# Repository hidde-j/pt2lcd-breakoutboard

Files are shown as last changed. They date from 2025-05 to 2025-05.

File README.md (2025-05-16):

# pt2lcd-breakoutboard
Simple LPM015M135A breakout board 

#### Voltage regulator

The LPM015M135A expects 4.5V on VDDP, so an LT3009 voltage regulator is included in the design that steps 5V down to 4.5V.

#### Missing footprints/symbols

The BM20B-24DS and LT3009 footprints are not included due to copyright reasons. These can be found by searching for the part numbers on Digikey. These are the expected file locations:

```
.
├── BM20B-24DS
│   ├── 2024-12-25_12-01-17.kicad_sym
│   ├── BM20B(0.6)-24DS-0.4V(53).STEP
│   └── footprints.pretty
│       └── BM20B0.6-24DS-0.4V53_HIR.kicad_mod
├── LT3009
│   ├── 2024-12-23_21-50-19.kicad_sym
│   ├── 3009fd.pdf
│   └── footprints.pretty
│       ├── DFN-6_DC_LIT.kicad_mod
│       ├── DFN-6_DC_LIT-L.kicad_mod
│       └── DFN-6_DC_LIT-M.kicad_mod
```

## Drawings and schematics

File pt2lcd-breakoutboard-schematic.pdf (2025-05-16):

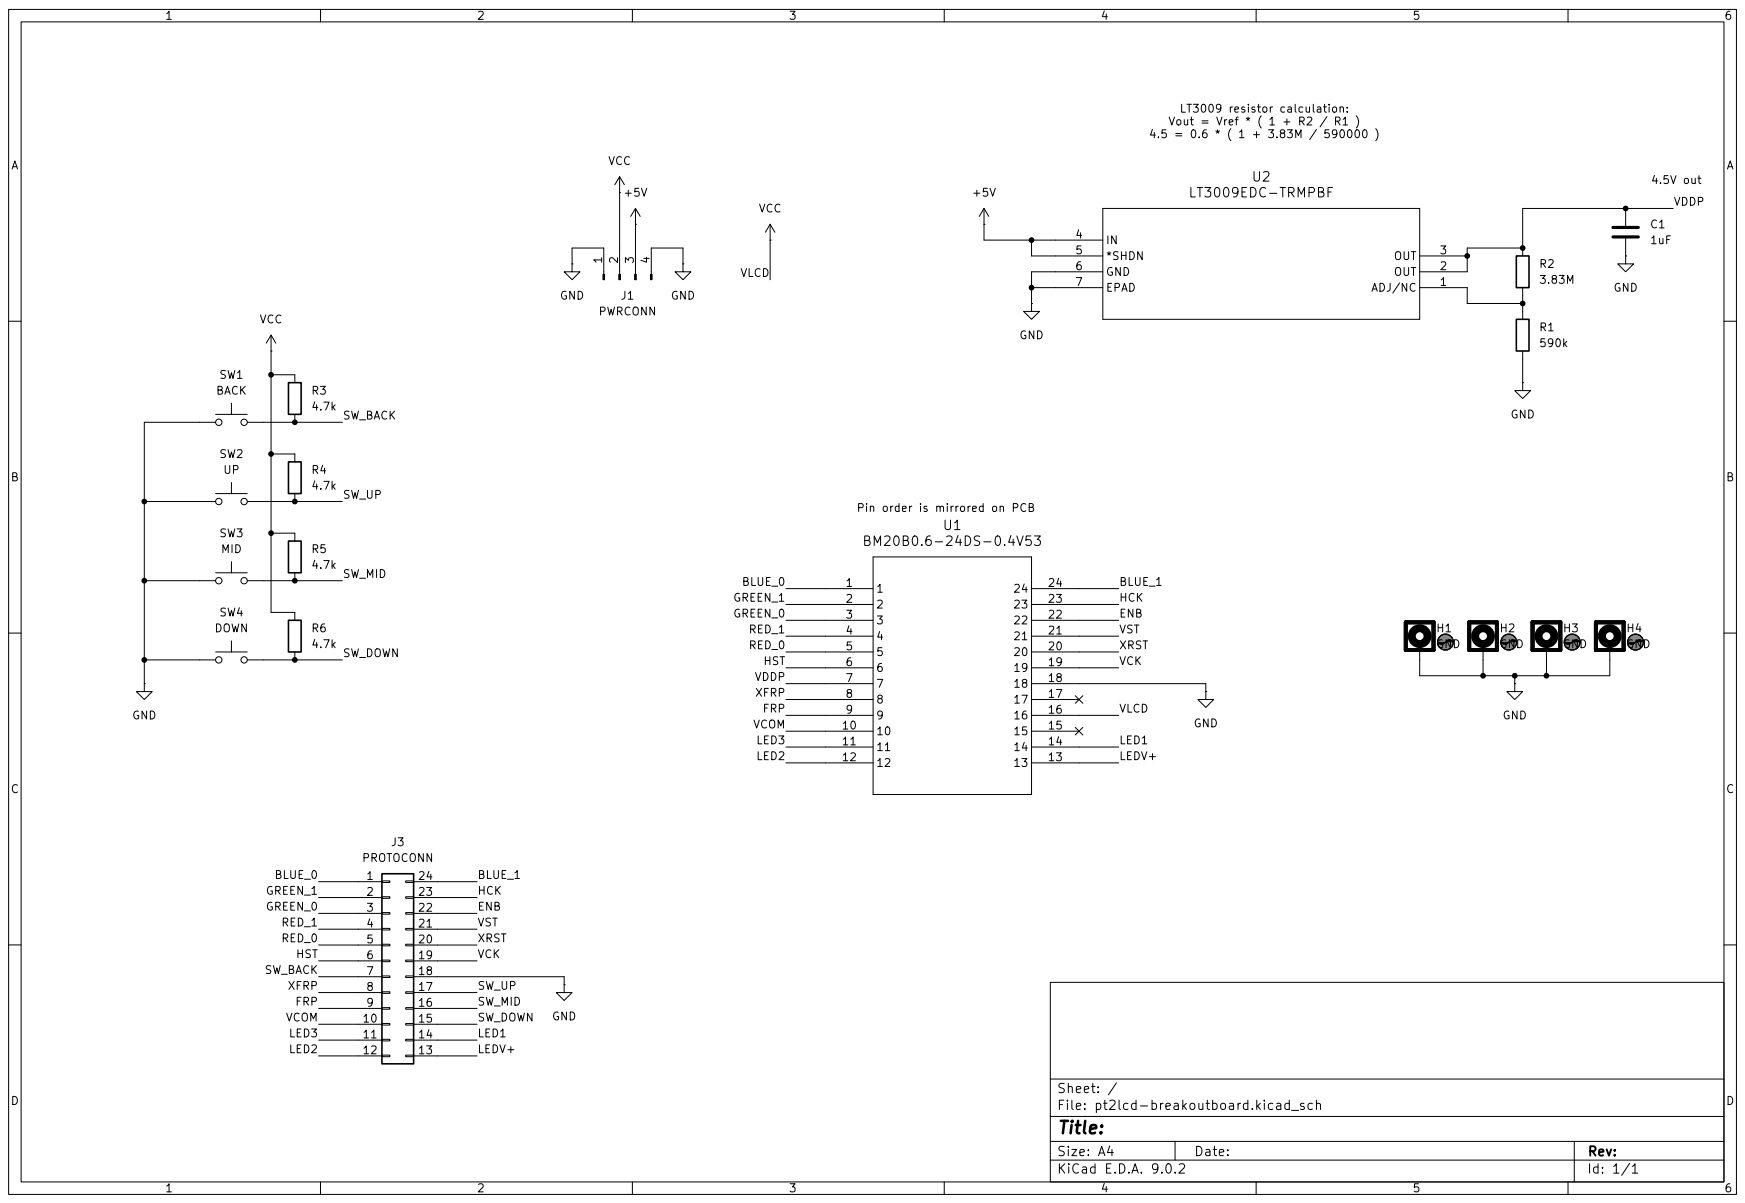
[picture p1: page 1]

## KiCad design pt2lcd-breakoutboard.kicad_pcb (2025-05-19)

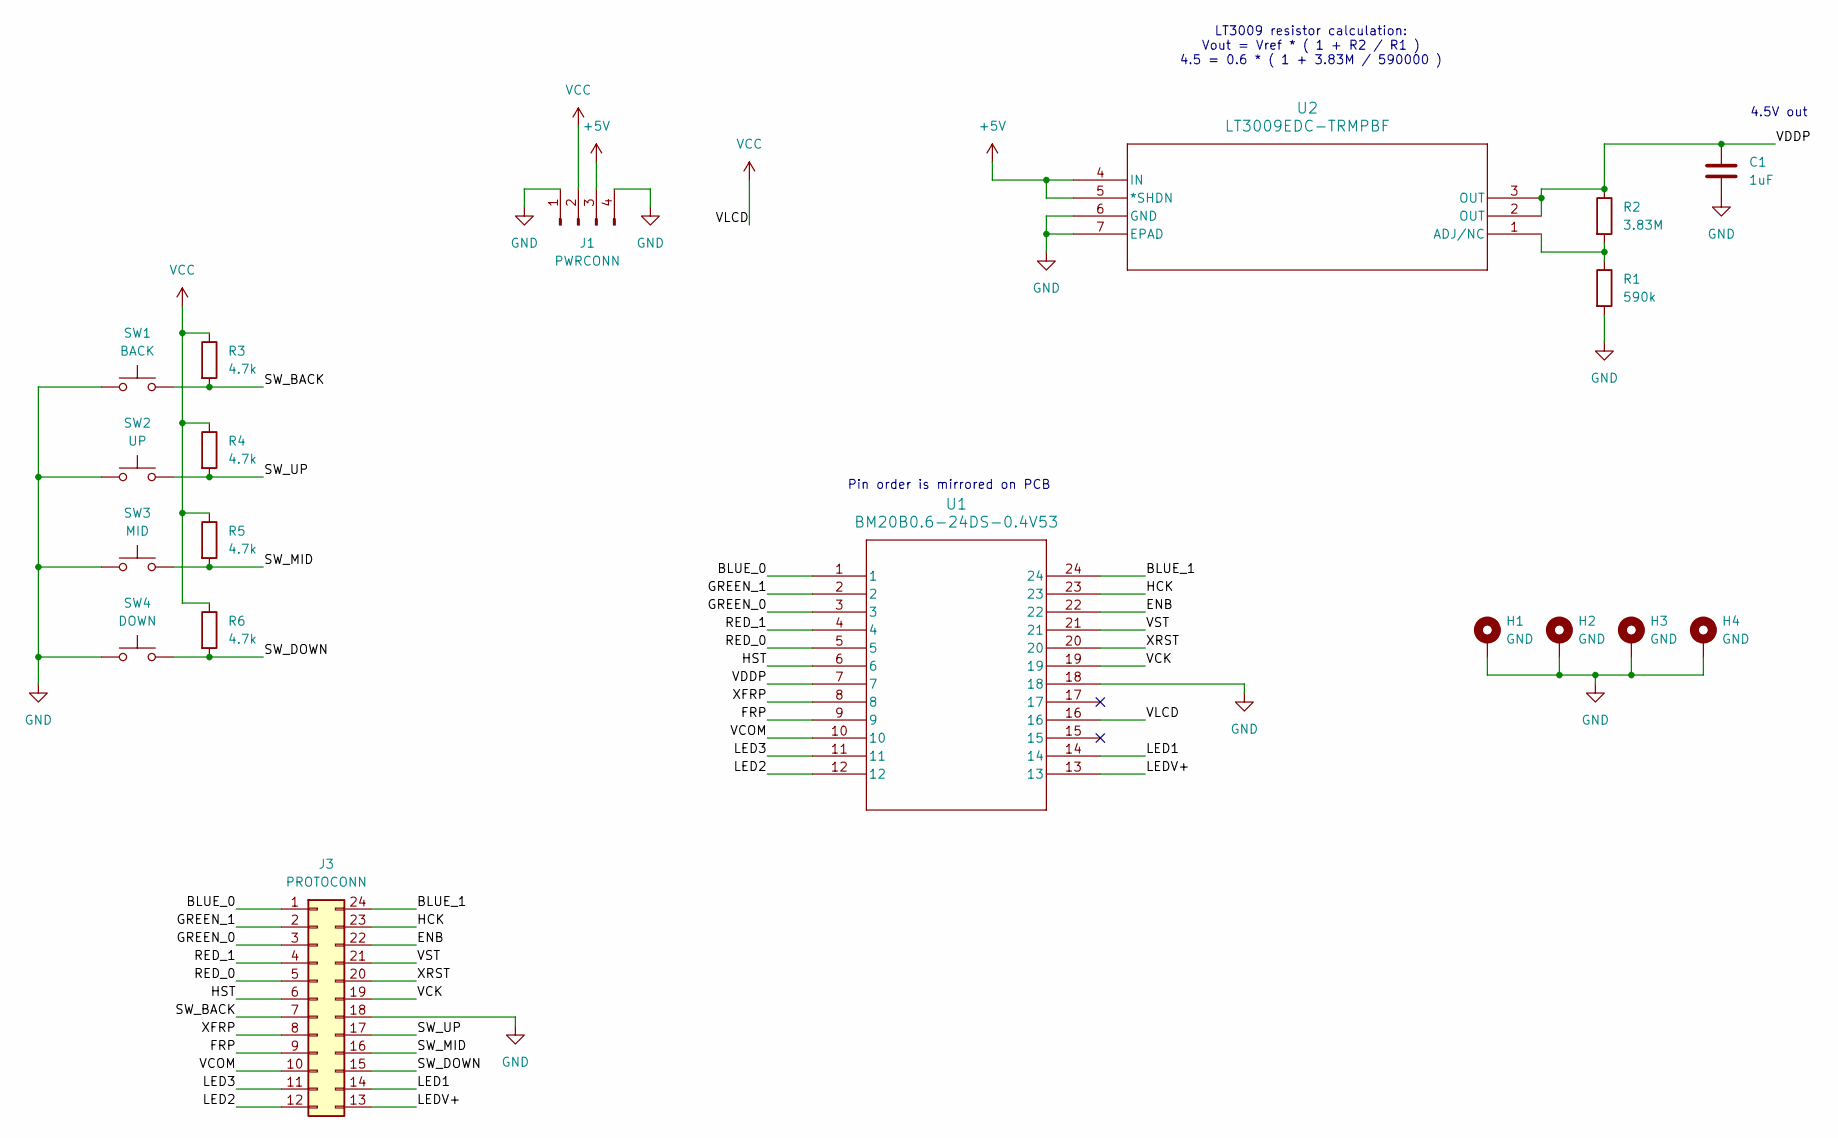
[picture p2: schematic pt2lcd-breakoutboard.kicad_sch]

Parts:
C1: 1uF; C_0603_1608Metric; LCSC C15849
H1, H2, H3, H4: GND; MountingHole_3.5mm_Pad
J1: PWRCONN; PinHeader_1x04_P2.54mm_Vertical
J3: PROTOCONN; PinHeader_2x12_P2.54mm_Vertical
R1: 590k; R_0603_1608Metric; LCSC C5126105
R2: 3.83M; R_0603_1608Metric; LCSC C482841
R3, R4, R5, R6: 4.7k; R_0603_1608Metric; LCSC C23162
SW1: BACK; SW_SPST_SKQG_WithStem
SW2: UP; SW_SPST_SKQG_WithStem
SW3: MID; SW_SPST_SKQG_WithStem
SW4: DOWN; SW_SPST_SKQG_WithStem
U1: BM20B0.6-24DS-0.4V53; BM20B0.6-24DS-0.4V53_HIR
U2: LT3009EDC-TRMPBF; DFN-6_DC_LIT; LCSC C666166

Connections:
+5V: J1.3, U2.4 (IN), U2.5 (*SHDN)
/BLUE_0: J3.1, U1.1
/BLUE_1: J3.24, U1.24
/ENB: J3.22, U1.22
/FRP: J3.9, U1.9
/GREEN_0: J3.3, U1.3
/GREEN_1: J3.2, U1.2
/HCK: J3.23, U1.23
/HST: J3.6, U1.6
/LED1: J3.14, U1.14
/LED2: J3.12, U1.12
/LED3: J3.11, U1.11
/LEDV+: J3.13, U1.13
/RED_0: J3.5, U1.5
/RED_1: J3.4, U1.4
/SW_BACK: J3.7, R3.2, SW1.2
/SW_DOWN: J3.15, R6.2, SW4.2
/SW_MID: J3.16, R5.2, SW3.2
/SW_UP: J3.17, R4.2, SW2.2
/VCK: J3.19, U1.19
/VCOM: J3.10, U1.10
/VDDP: C1.1, R2.1, U1.7, U2.2 (OUT), U2.3 (OUT)
/VST: J3.21, U1.21
/XFRP: J3.8, U1.8
/XRST: J3.20, U1.20
GND: C1.2, H1.1, H2.1, H3.1, H4.1, J1.1, J1.4, J3.18, R1.2, SW1.1, SW2.1, SW3.1, SW4.1, U1.18, U2.6 (GND), U2.7 (EPAD)
unnamed: R1.1, R2.2, U2.1 (ADJ/NC)
VCC: J1.2, R3.1, R4.1, R5.1, R6.1, U1.16

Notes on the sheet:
Pin order is mirrored on PCB
LT3009 resistor calculation: Vout = Vref * ( 1 + R2 / R1 ) 4.5 = 0.6 * ( 1 + 3.83M / 590000 )
4.5V out

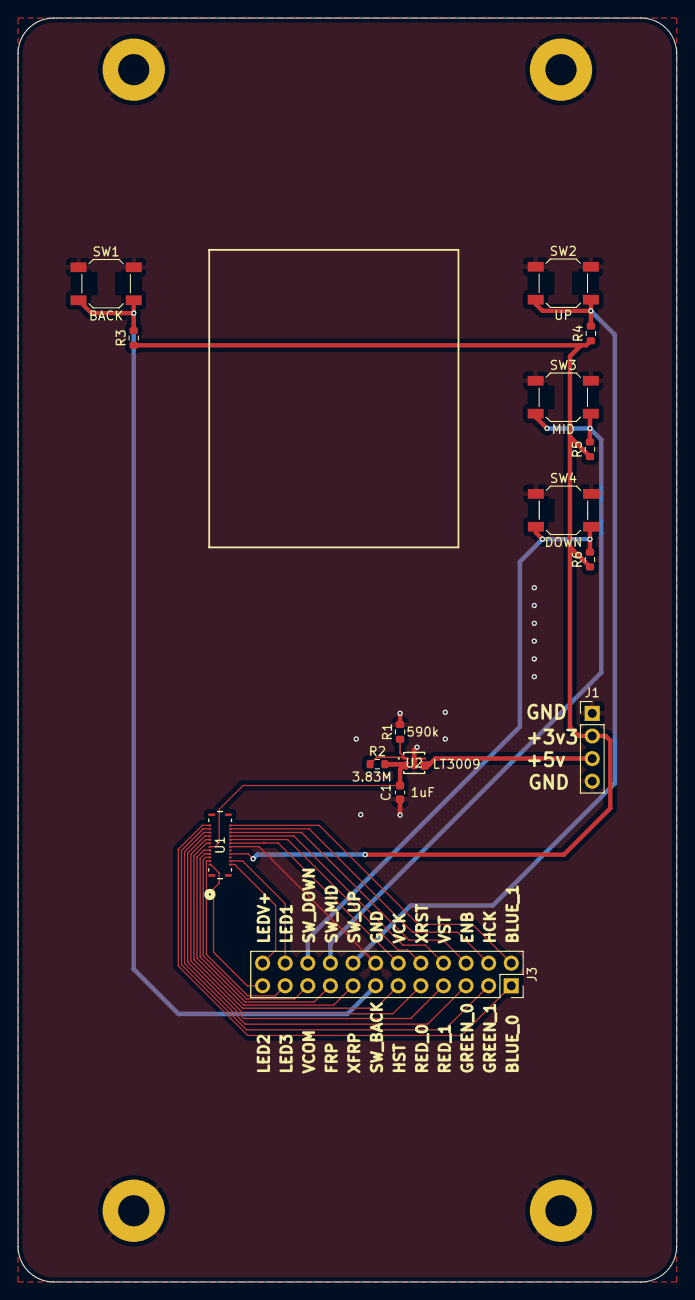
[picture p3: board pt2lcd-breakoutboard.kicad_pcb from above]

Board: 2 copper layers, 74.0 x 142.0 mm, 19 parts (0 on the bottom side), 28 nets.
